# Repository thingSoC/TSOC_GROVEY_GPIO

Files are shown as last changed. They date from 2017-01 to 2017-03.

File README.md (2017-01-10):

# TSOC_GROVEY_GPIO - thingSoC SX1509 GPIO Module :

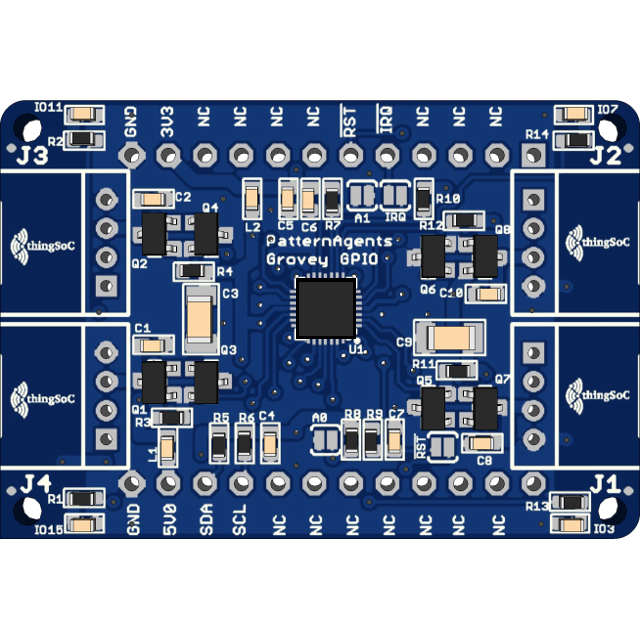
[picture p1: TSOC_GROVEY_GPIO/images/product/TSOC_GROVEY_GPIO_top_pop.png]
thingSoC TSOC_GROVEY_GPIO
[TSOC_GROVEY_GPIO](https://github.com/thingSoC/TSOC_GROVEY_GPIO)

---------------------------------------

## TSOC_GROVEY_GPIO Status <a name="TSOC_GROVEY_GPIO_status"/>

**11/06/2016:** 
Revision 1.0 - Initial Layout released to OSHpark

---------------------------------------
## TSOC_GROVEY_GPIO Model Images

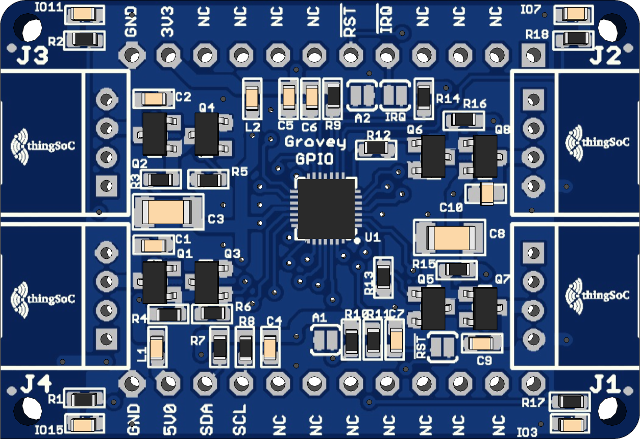
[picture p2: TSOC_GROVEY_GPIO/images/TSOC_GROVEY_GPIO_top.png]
thingSoC TSOC_GROVEY_GPIO
[TSOC_GROVEY_GPIO](https://github.com/thingSoC/TSOC_GROVEY_GPIO)

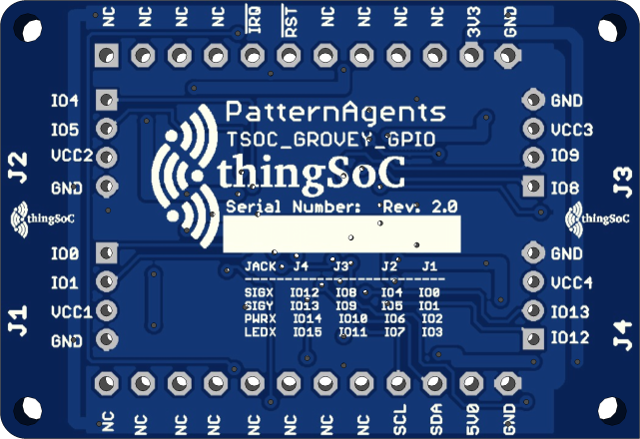
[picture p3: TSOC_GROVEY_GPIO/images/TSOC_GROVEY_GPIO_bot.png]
thingSoC TSOC_GROVEY_GPIO
[TSOC_GROVEY_GPIO](https://github.com/thingSoC/TSOC_GROVEY_GPIO)

---------------------------------------

## TSOC_GROVEY_GPIO Documentation Index <a name="TSOC_GROVEY_GPIO_documentation_index"/>

[TSOC_GROVEY_GPIO Project](http://thingsoc.github.io/projects/TSOC_GROVEY_GPIO.html)

[TSOC_GROVEY_GPIO Hardware](https://github.com/thingSoC/TSOC_GROVEY_GPIO/tree/master/TSOC_GROVEY_GPIO/hardware)

---------------------------------------

## thingSoC Documentation Index <a name="thingSoC_documentation_index"/>

[thingSoC Organization Website](http://thingSoC.github.io)

[thingSoC FAQ - Frequently Asked Questions](http://thingsoc.github.io/support/faq.html)

---------------------------------------

[thingSoC 
*thingSoC*](http://thingsoc.github.io)

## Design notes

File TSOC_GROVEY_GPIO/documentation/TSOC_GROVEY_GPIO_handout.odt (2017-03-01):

thingSoC GROVEY_GPIO Board

Thank you for purchasing a TSOC_GROVEY_GPIO board!
Please see the Getting Started Guide at :
https://github.com/thingSoC/TSOC_GROVEY_GPIO (https://github.com/thingSoC/TSOC_NEOLED)
It has complete instructions and examples to download.

thingSoC GROVEY_GPIO Board

Thank you for purchasing a TSOC_GROVEY_GPIO board!
Please see the Getting Started Guide at :
https://github.com/thingSoC/TSOC_GROVEY_GPIO (https://github.com/thingSoC/TSOC_NEOLED)
It has complete instructions and examples to download.

thingSoC GROVEY_GPIO Board

Thank you for purchasing a TSOC_GROVEY_GPIO board!
Please see the Getting Started Guide at :
https://github.com/thingSoC/TSOC_GROVEY_GPIO (https://github.com/thingSoC/TSOC_NEOLED)
It has complete instructions and examples to download.

thingSoC GROVEY_GPIO Board

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

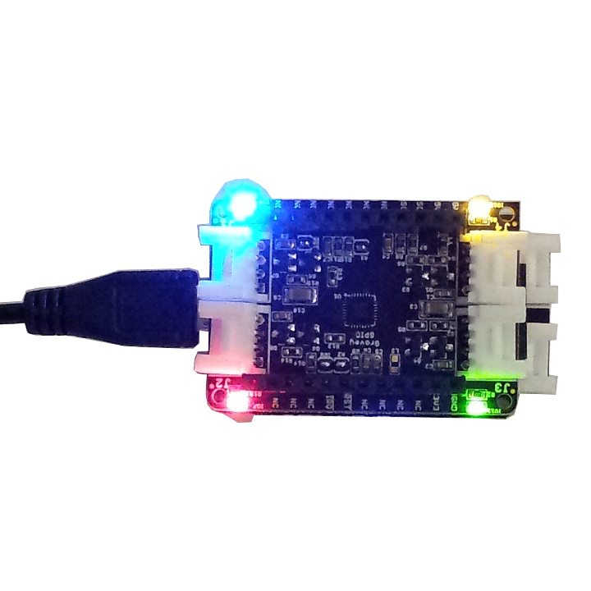
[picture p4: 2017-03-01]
TSOC_GROVEY_GPIO/images/product/tsoc_grovey_gpio_sqr.jpg

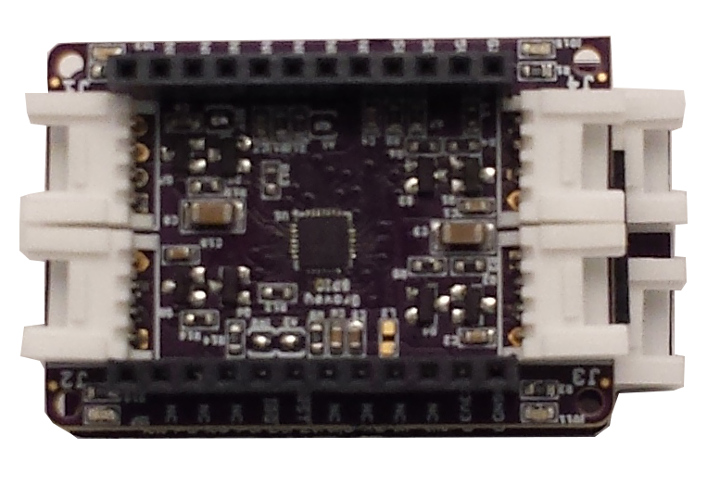
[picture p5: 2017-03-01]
TSOC_GROVEY_GPIO/images/product/tsoc_grovey_gpio.jpg

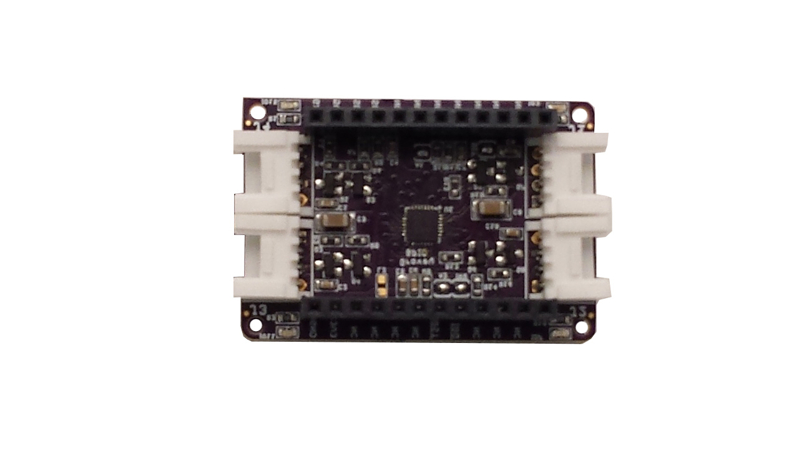
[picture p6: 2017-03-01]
TSOC_GROVEY_GPIO/images/product/tsoc_grovey_gpio3.jpg

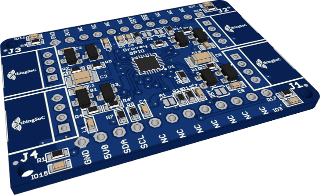
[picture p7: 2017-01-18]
TSOC_GROVEY_GPIO/images/TSOC_GROVEY_GPIO_model.png

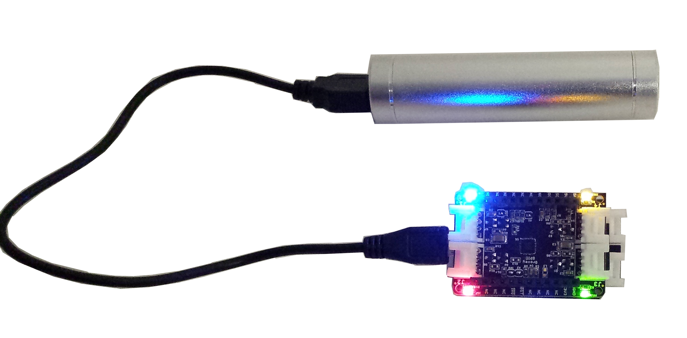
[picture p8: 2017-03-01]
TSOC_GROVEY_GPIO/images/product/tsoc_grovey_gpio_full.jpg

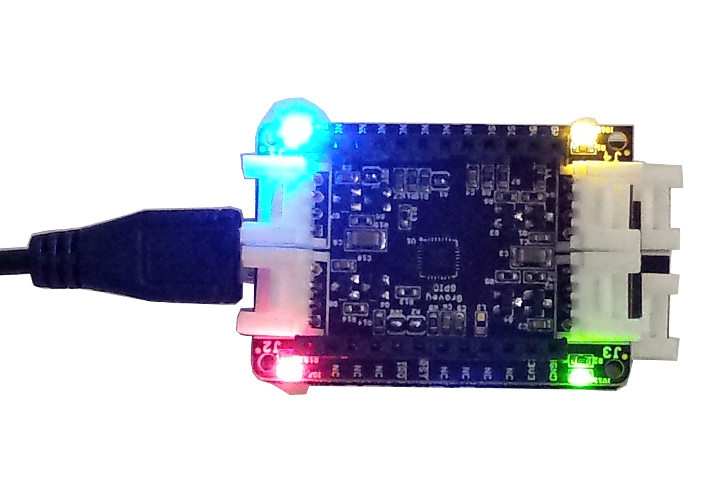
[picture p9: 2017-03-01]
TSOC_GROVEY_GPIO/images/product/tsoc_grovey_gpio2.jpg

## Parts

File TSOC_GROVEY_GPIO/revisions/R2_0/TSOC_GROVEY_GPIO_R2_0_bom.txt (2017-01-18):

Partlist exported from U:/PatternAgents/eagle/TSOC_Modules/TSOC_GROVEY_GPIO/TSOC_GROVEY_GPIO/revisions/R2_0/TSOC_GROVEY_GPIO.sch at 1/17/2017 9:49:19 AM

Qty Value             Device                                        Package         Parts                              Description                         
1   BLUE-0603         SMD-LED-CLEAR-BLUE(0603)                      LED-0603        IO3                                304090045                           
1   RED-0603          LED-SMD-RED-DIFFUSED(0603)                    LED-0603        IO7                                304090042                           
1   GREEN-0603        SMD-LED-CLEAR-GREEN(0603)                     LED-0603        IO11                               304090043                           
1   YELLOW-0603       SMD-LED-CLEAR-YELLOW(0603)                    LED-0603        IO15                               304090044                           
1   SX1509            SX1509                                        QFN-28          U1                                 Semtech SX1509                      
4   BSS138W-7-F       SMD-MOSFET-N-CH-50V-200MA-BSS138W-7-F(SOT-23) SOT-23          Q3, Q4, Q5, Q6                     305030000                           
4   CJ2305            SMD-MOSFET-P-CH-8V-4.1A-CJ2305(SOT-23)        SOT-23          Q1, Q2, Q7, Q8                     305030014                           
2   100nf             CERAMIC-100NF-50V-10%-X7R(0603)               C0603           C5, C7                             302010138                           
6   1uf               CERAMIC-1UF-25V-10%-X7R(0603)                 C0603           C1, C2, C4, C6, C9, C10            302010139                           
2   10uf              CERAMIC-10UF-25V-10%-X5R(1206)                C1206           C3, C8                             302010181                           
6   10K 1/10W         SMD-RES-10K-5%-1/10W(0603)                    R0603           R7, R8, R9, R10, R11, R14          301010293                           
4   1K 1/10W          SMD-RES-1K-5%-1/10W(0603)                     R0603           R1, R2, R17, R18                   301010291                           
8   47K               SMD-RES-47K-5%-1/10W(0603)                    R0603           R3, R4, R5, R6, R12, R13, R15, R16 301010084                           
4   4P-2.0-90D        GROVE-CONNECTOR-DIP-90D(4P-2.0)               HW4-2.0-90D     J1, J2, J3, J4                     320110034                           
1   120OHM-500MA      SMD-FERRITE-CHIP-120-OHM-500MA(0603)          L0603           L1                                 303030001                           
=--------------------------------------------------------------------------------------------------------------------------------
1   DNP               SMD-FERRITE-CHIP-120-OHM-500MA(0603)          L0603           L2                                 303030001

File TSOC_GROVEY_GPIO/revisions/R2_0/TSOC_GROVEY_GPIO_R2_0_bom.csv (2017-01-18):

Part/Designator | Manufacture Part Number/Seeed SKU | Quantity
IO3 | 304090045 | 1
IO7 | 304090042 | 1
IO11 | 304090043 | 1
IO15 | 304090044 | 1
U1 | SX1509IULTRT | 1
Q3, Q4, Q5, Q6 | 305030000 | 4
Q1, Q2, Q7, Q8 | 305030014 | 4
C5, C7 | 302010138 | 2
C1, C2, C4, C6, C9, C10 | 302010139 | 6
C3, C8 | 302010181 | 2
R7, R8, R9, R10, R11, R14 | 301010293 | 6
R1, R2, R17, R18 | 301010291 | 4
R3, R4, R5, R6, R12, R13, R15, R16 | 301010084 | 8
L1 | 303030001 | 1
J1, J2, J3, J4 | 320110034 | 4
J5, J6 | SSW-112-03-G-S | 2

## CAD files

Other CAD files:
TSOC_GROVEY_GPIO/eagleUp/TSOC_GROVEY_GPIO.skp

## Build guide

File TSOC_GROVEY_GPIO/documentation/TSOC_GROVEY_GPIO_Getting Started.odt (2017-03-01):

Welcome to the thingSoC® Grovey GPIO

The TSOC_GROVEY_GPIO is a sixteen (16) port I2C I/O Expander, based on the Semtech SX1509 chip, in an Embedded Module format for the new thingSoC, Internet of Things open source hardware standard.

Getting Started :
The TSOC_GROVEY_GPIO provides sixteen (16) I/O ports, with four(4) Grove compatible connectors. You can use the TSOC_GROVEY_GPIO when :

1. When you need to use 5.0 Volt level I/O with a 3.3V processor.
2. When you need more ports than the 3.3V processor can provide.
3. When you need to control the power of your grove peripherals.

The TSOC_GROVEY_GPIO is an open source hardware project from PatternAgents, LLC,
and you are free to download the schematics, layouts, gerbers, BOMs, etc and build your own boards if you wish.


Default Settings :

Default I2C Address : 0x3E
( Remove Jumper A0 to change address to 0X3F)

Semtech SX1509 I/O Assignment :

I/O 00 : J1 Signal X
I/O 01 : J1 Signal Y
I/O 02 : J1 Power Control
I/O 03 : J1 LED (BLUE)

I/O 04 : J2 Signal X
I/O 05 : J2 Signal Y
I/O 06 : J2 Power Control
I/O 07 : J2 LED (RED)

I/O 08 : J3 Signal X
I/O 09 : J3 Signal Y
I/O 10 : J3 Power Control
I/O 11 : J3 LED (GREEN)

I/O 12 : J4 Signal X
I/O 13 : J4 Signal Y
I/O 14 : J4 Power Control
I/O 15 : J4 LED (YELLOW)


Safe Handling Precautions :

1) Always remove/unplug all power before inserting or removing peripherals.
2) Always ground yourself by touching a ground point before handling your boards.
3) Use a static safe bag when transporting your TSOC_GROVEY_GPIO board.

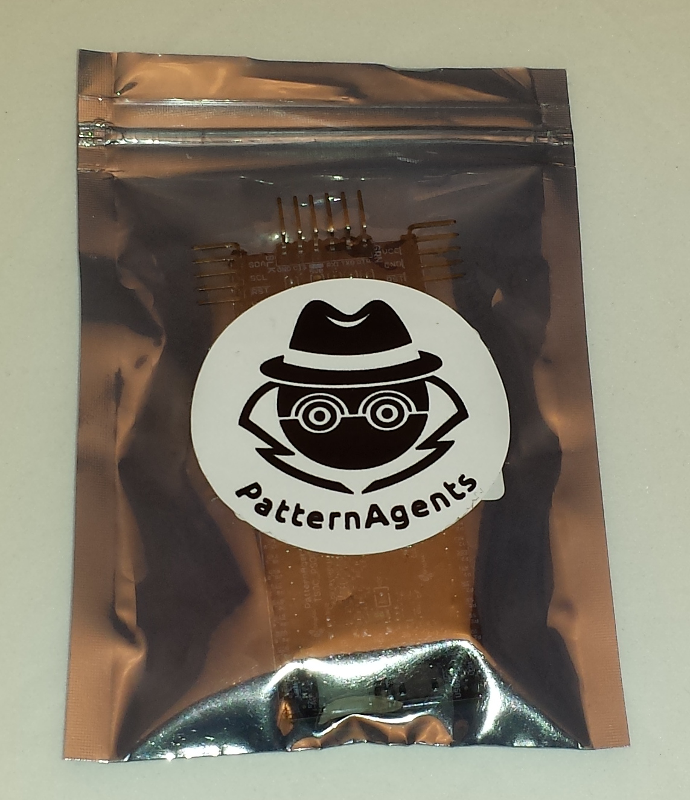
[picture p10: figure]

Adding Grove Peripherals :
The TSOC_GROVEY_GPIO board supports Grove peripherals.
1) Grove connectors are polarized, and can only be plugged in one way.

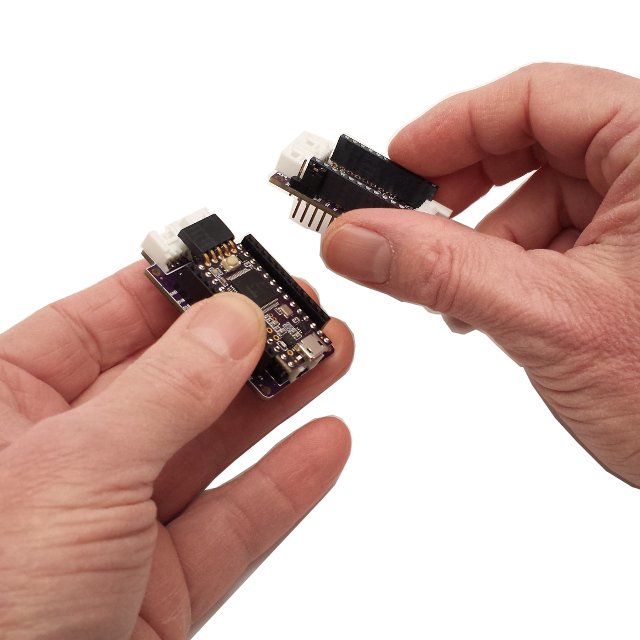
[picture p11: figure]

Adding Mikrobus Peripherals :
The TSOC_GROVEY_GPIO board supports Grove peripherals and can interoperate with Mikrobus peripherals.

1) Make sure to align the SQUARE/CUT edges of the Mikrobus board together to insure that
the polarity is correct. Push down evenly to seat the boards in the socket.

2) Note that the "stacking pins" are somewhat longer by design, and there will be some
extra space between the boards when using stacking connectors.

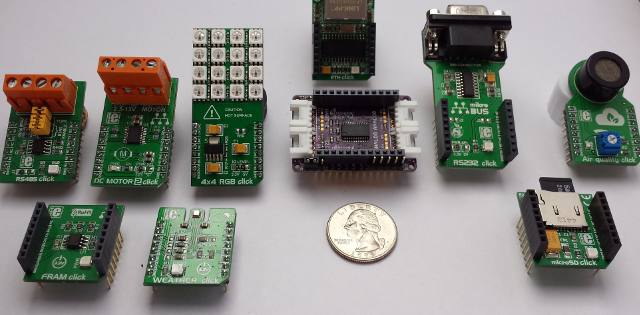
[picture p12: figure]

For more information and examples :

Complete documentation, including schematics, layouts, gerbers, and Bill of Materials (BOM) are available on the thingSoC website at :

https://github.com/thingSoC/TSOC_GROVEY_GPIO/tree/master/TSOC_GROVEY_GPIO (https://github.com/thingSoC/TSOC_PSoC4L/tree/master/TSOC_PSoC4L)

There is also a project Wiki available for asking questions and more information at :

https://github.com/thingSoC/TSOC_GROVEY_GPIO/wiki (https://github.com/thingSoC/TSOC_PSoC4L/wiki)

thingSoC® Grovey GPIO Features :

The TSOC_GROVEY_GPIO is a low cost, embeddable module featuring a Semtech SX1509 device :

- 16 Port I2C GPIO Expander
- 0 Hz to 400KHz I2C Bus Speed
- 3.3 Volt or 5.0 Volt operation
- Optional Active Low Reset Line
- Low Standby current
- Builtin ESD protection
- GPIO (16 Channels)
- Four (4) Color LEDs (Red, Green, Blue, Yellow)
- thingSoC Compliant Module
- Mikrobus Compatible Module (http://www.mikroe.com/mikrobus/)
- Support SeeedStudio Grove Peripherals

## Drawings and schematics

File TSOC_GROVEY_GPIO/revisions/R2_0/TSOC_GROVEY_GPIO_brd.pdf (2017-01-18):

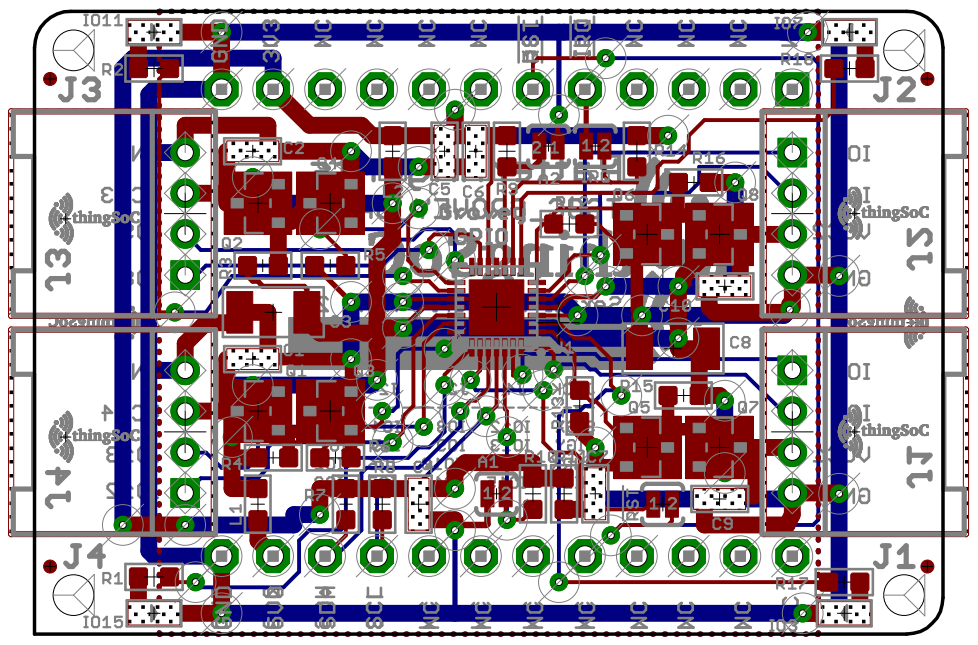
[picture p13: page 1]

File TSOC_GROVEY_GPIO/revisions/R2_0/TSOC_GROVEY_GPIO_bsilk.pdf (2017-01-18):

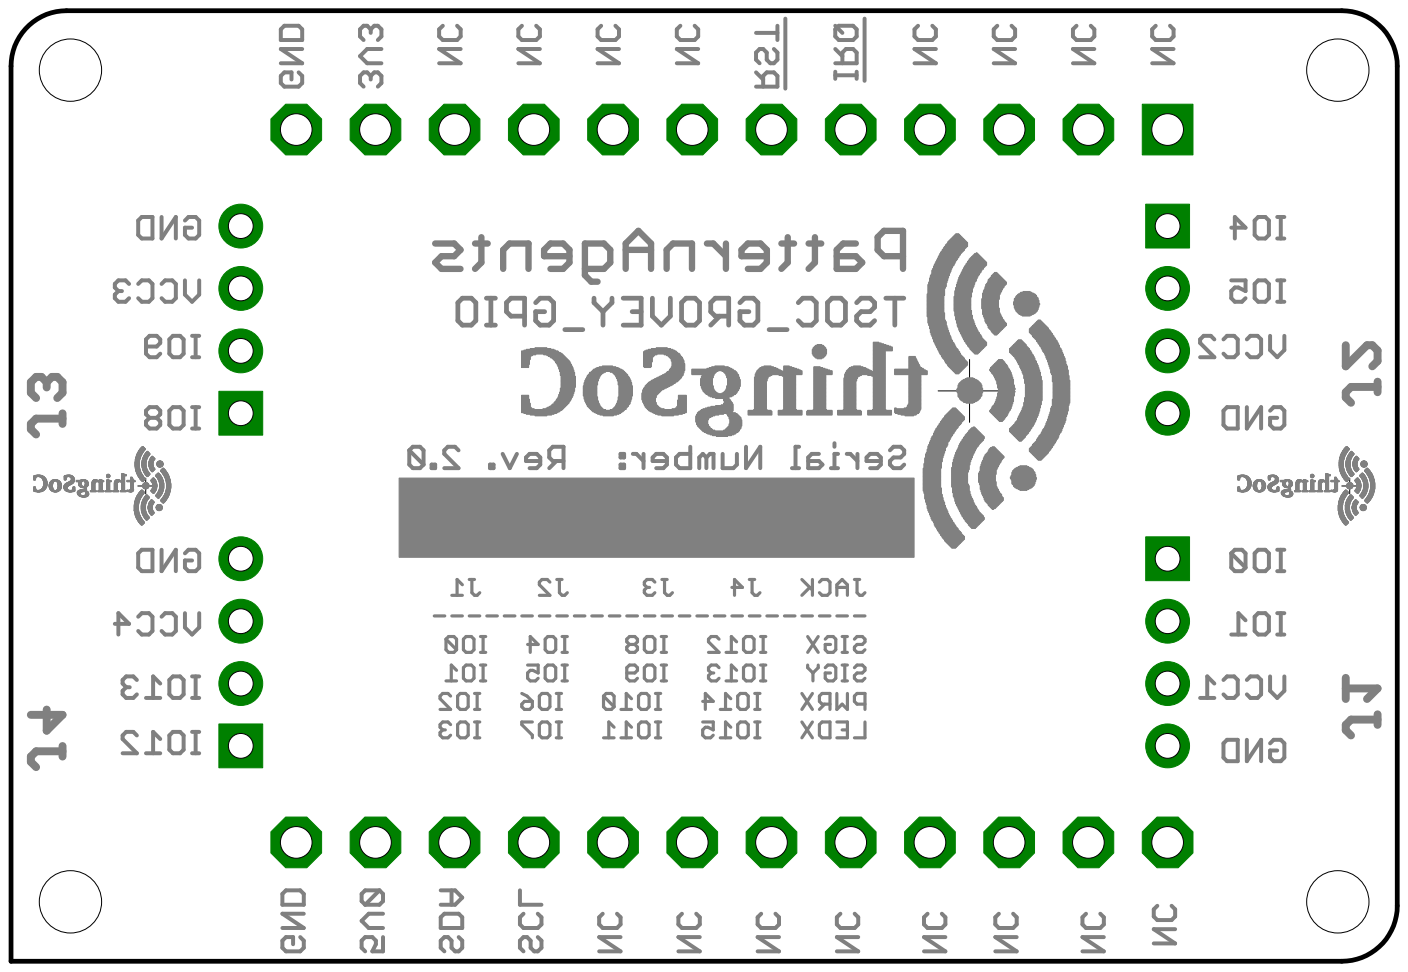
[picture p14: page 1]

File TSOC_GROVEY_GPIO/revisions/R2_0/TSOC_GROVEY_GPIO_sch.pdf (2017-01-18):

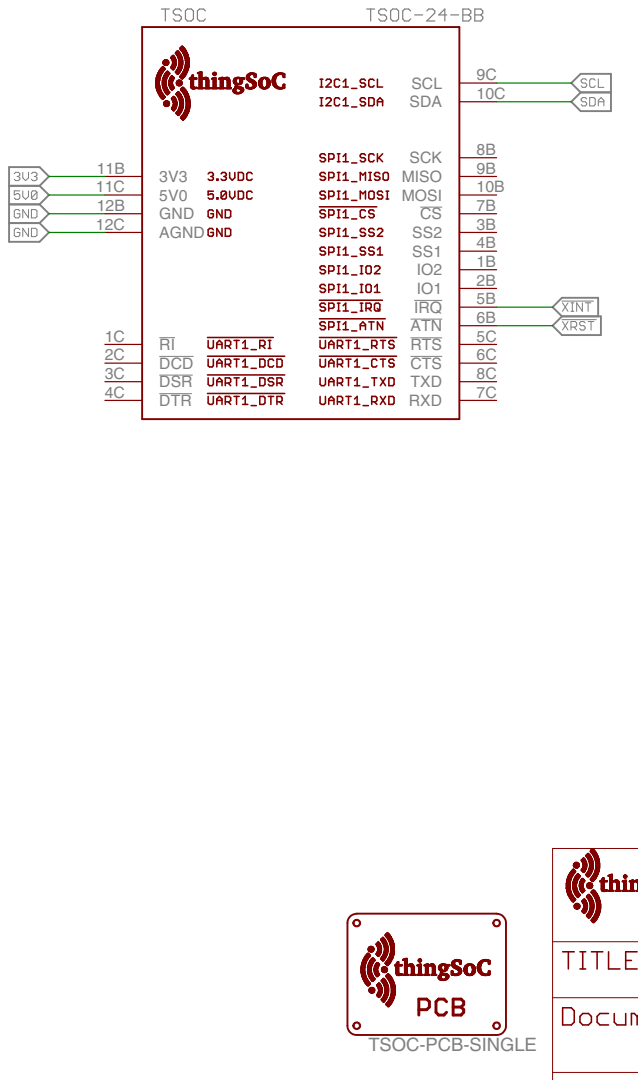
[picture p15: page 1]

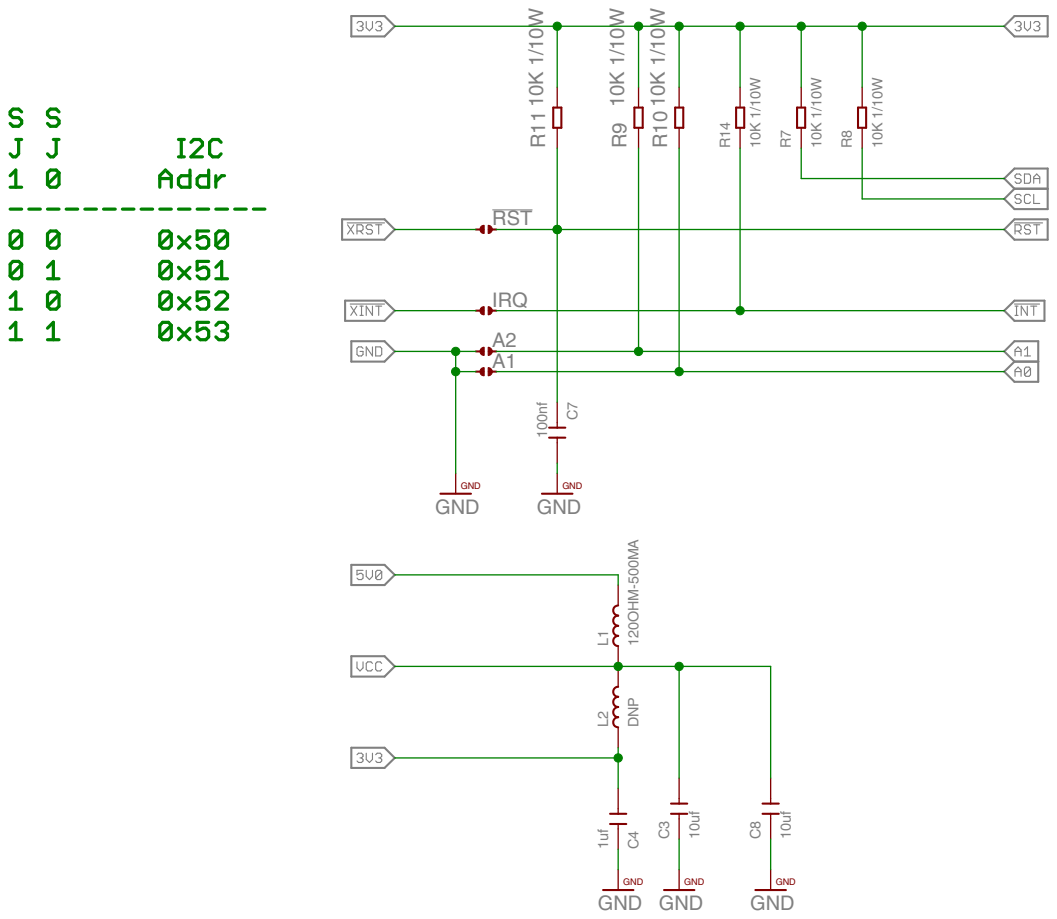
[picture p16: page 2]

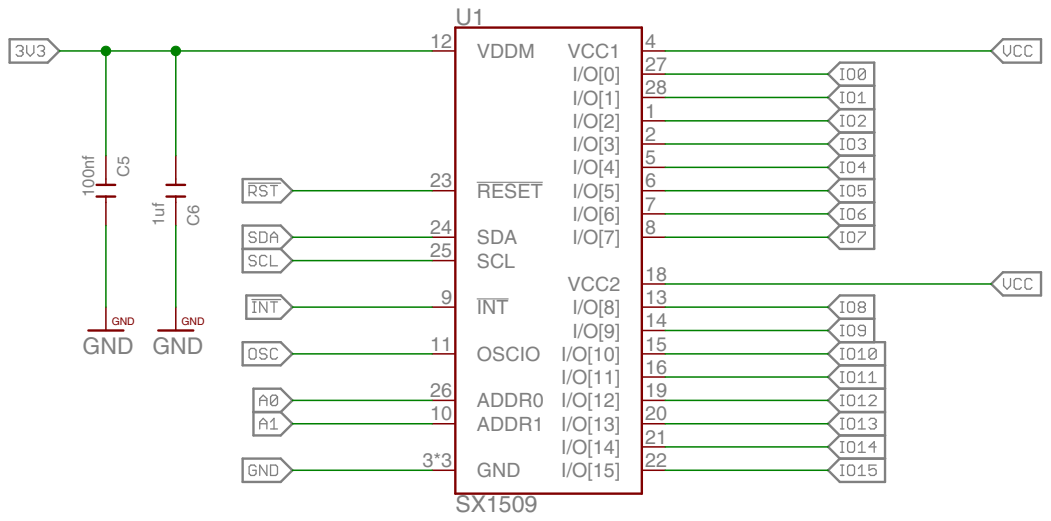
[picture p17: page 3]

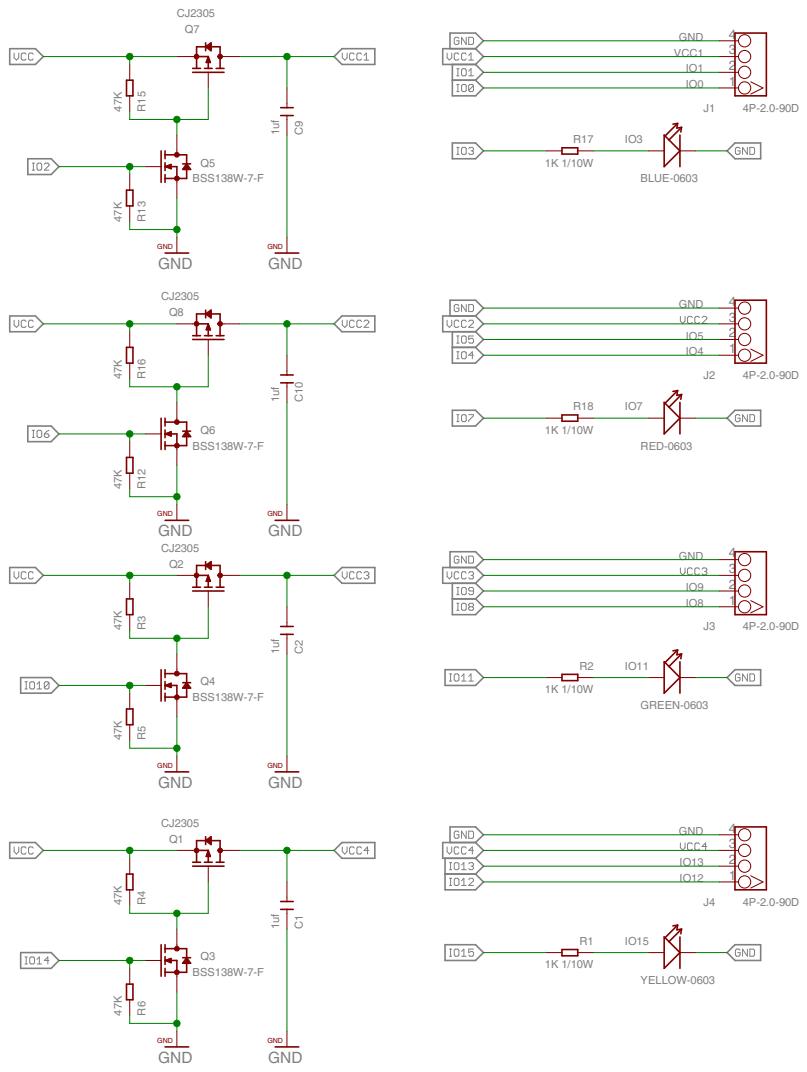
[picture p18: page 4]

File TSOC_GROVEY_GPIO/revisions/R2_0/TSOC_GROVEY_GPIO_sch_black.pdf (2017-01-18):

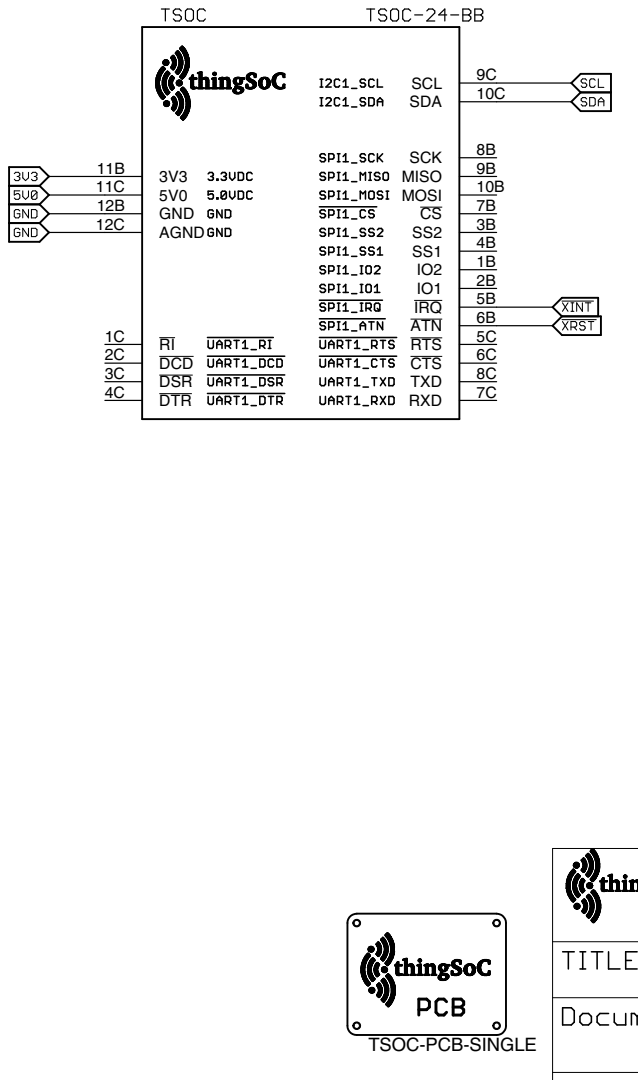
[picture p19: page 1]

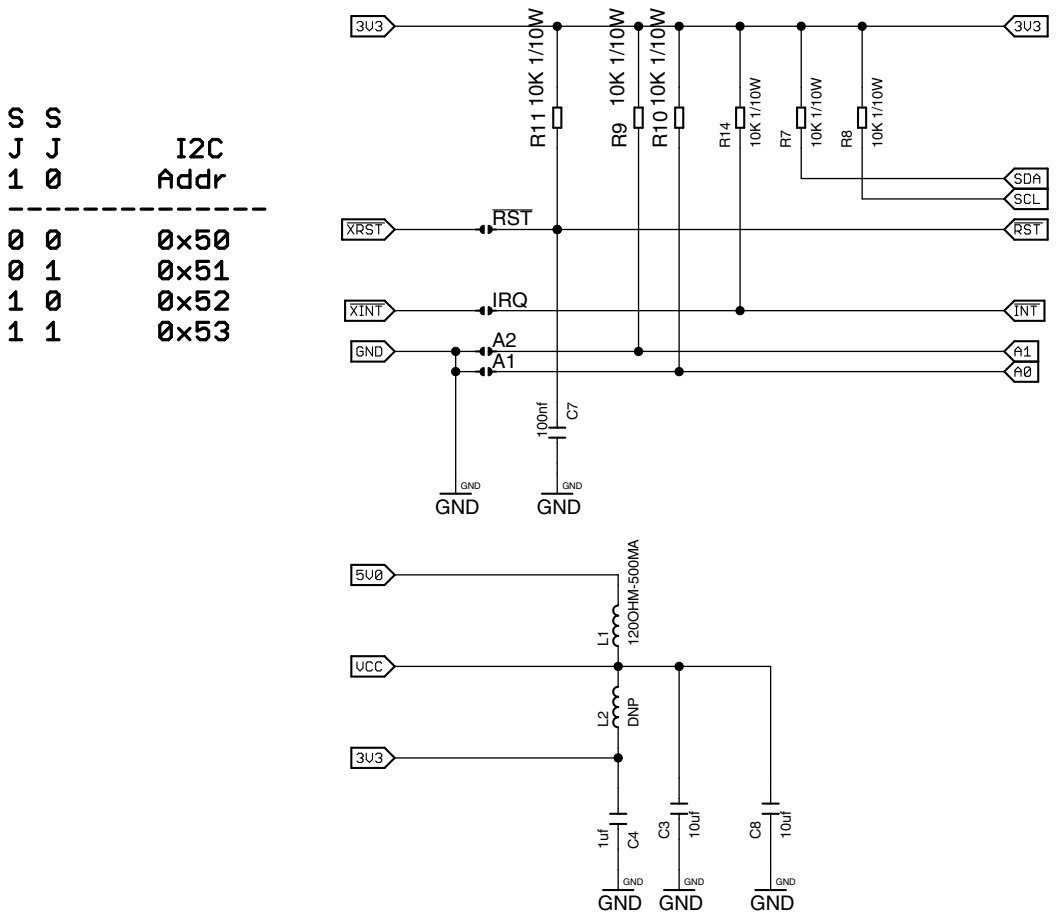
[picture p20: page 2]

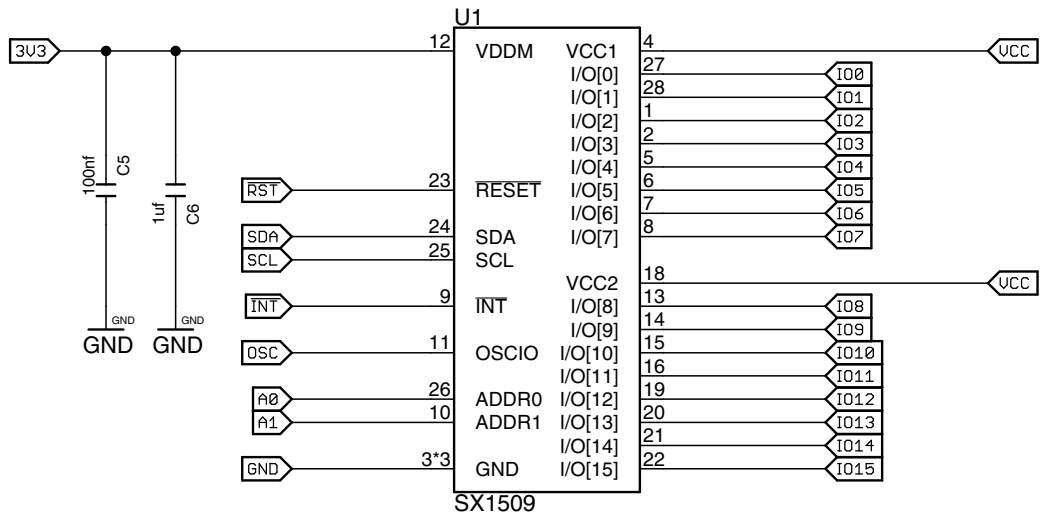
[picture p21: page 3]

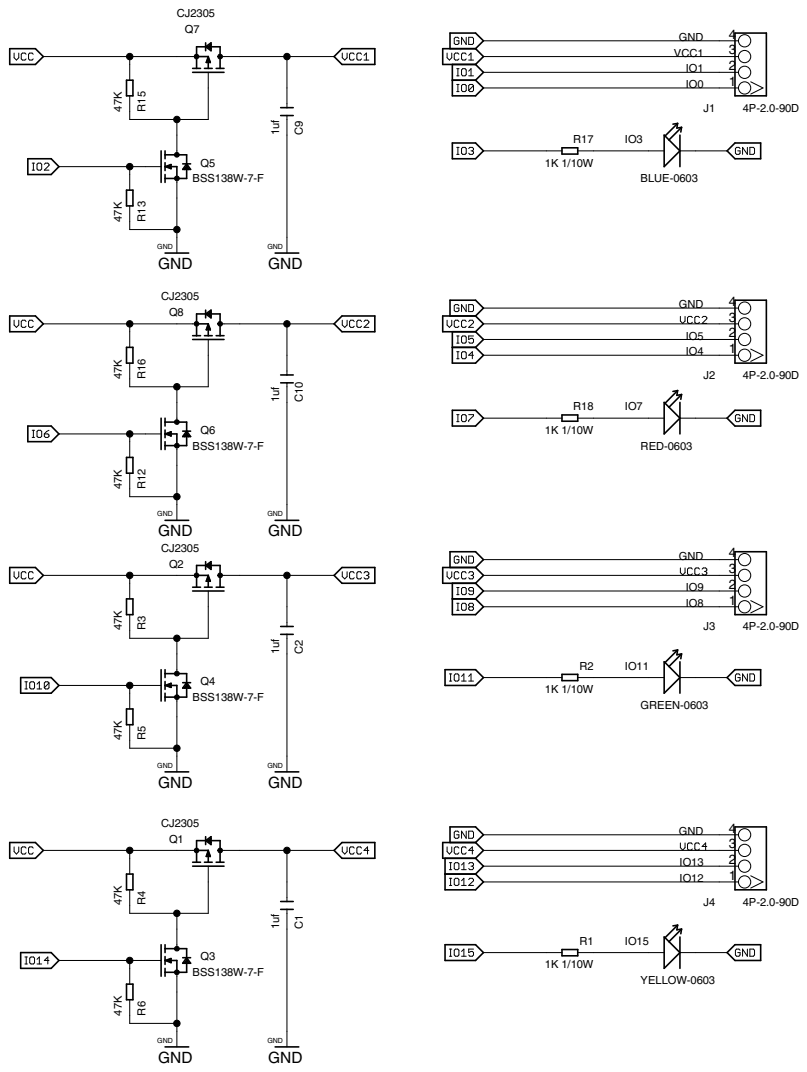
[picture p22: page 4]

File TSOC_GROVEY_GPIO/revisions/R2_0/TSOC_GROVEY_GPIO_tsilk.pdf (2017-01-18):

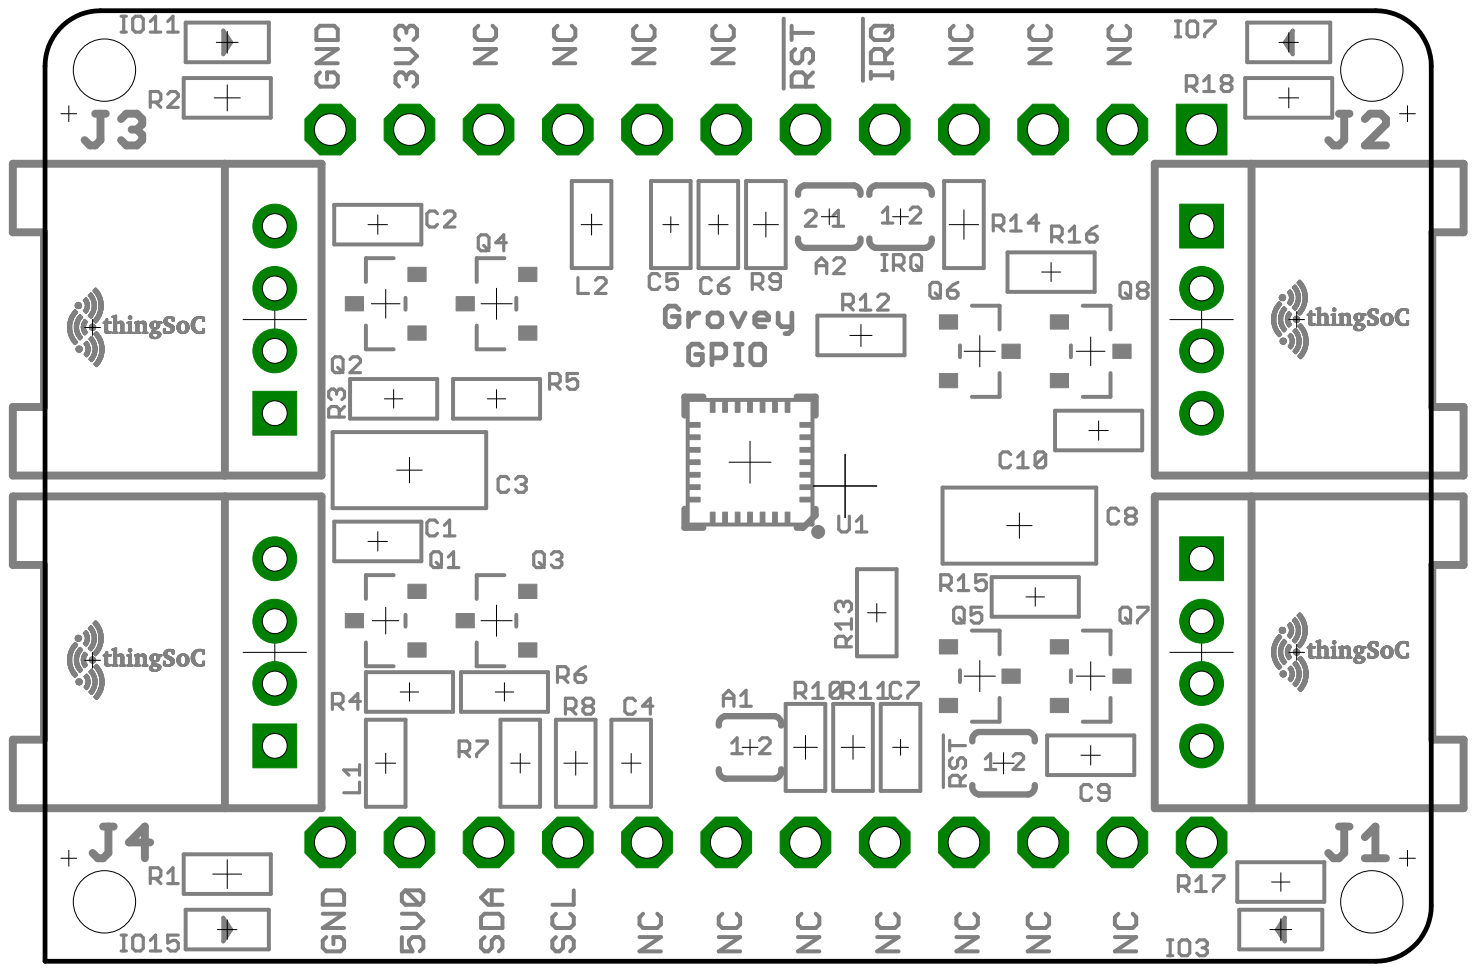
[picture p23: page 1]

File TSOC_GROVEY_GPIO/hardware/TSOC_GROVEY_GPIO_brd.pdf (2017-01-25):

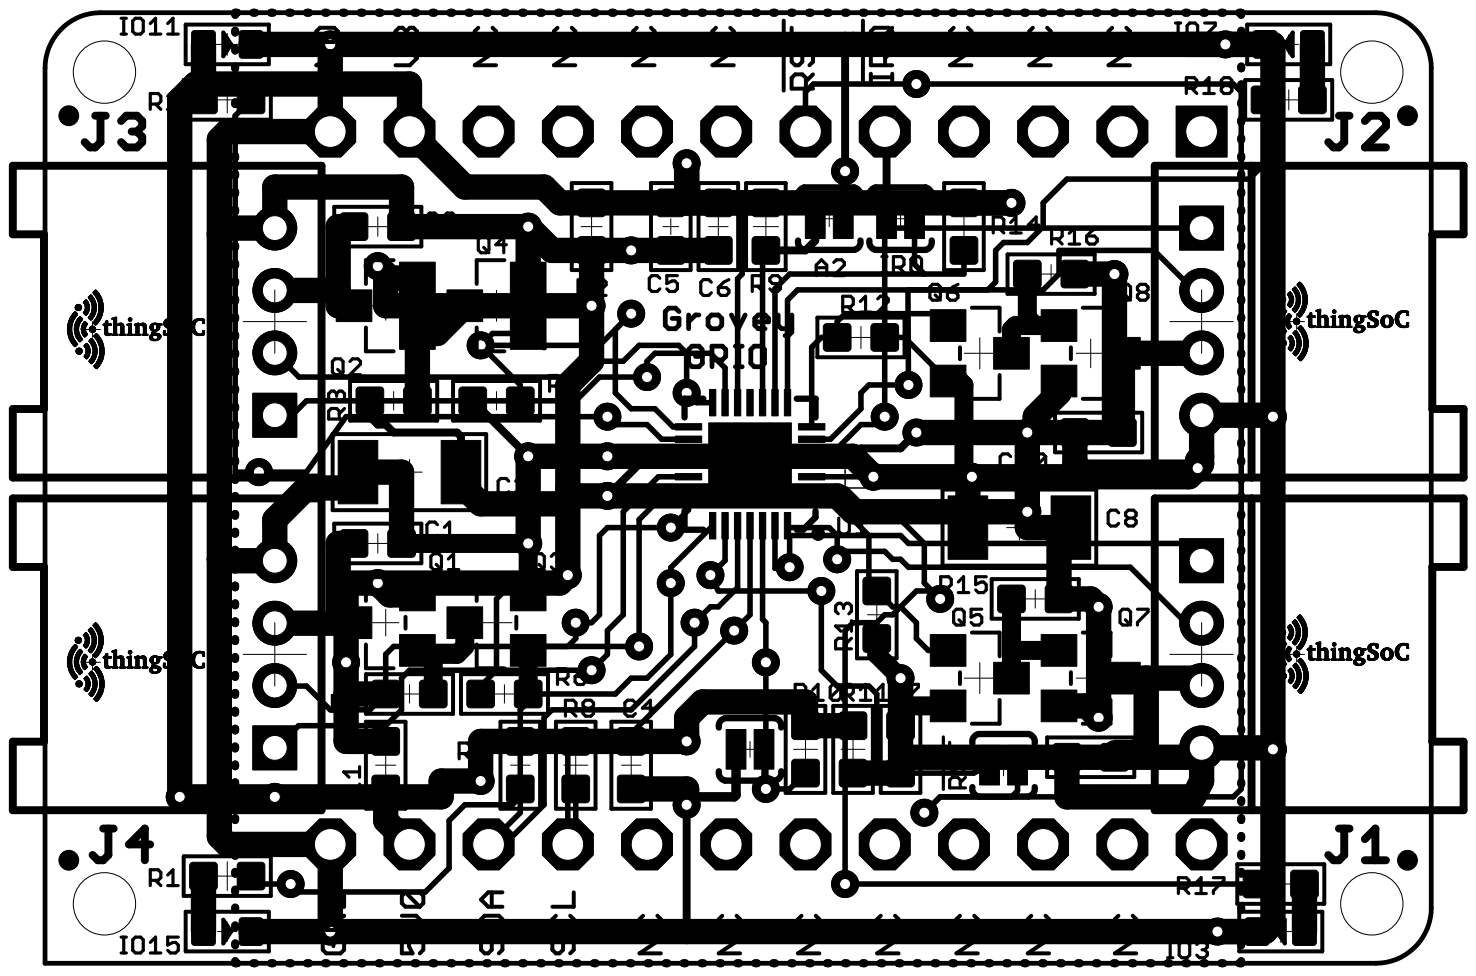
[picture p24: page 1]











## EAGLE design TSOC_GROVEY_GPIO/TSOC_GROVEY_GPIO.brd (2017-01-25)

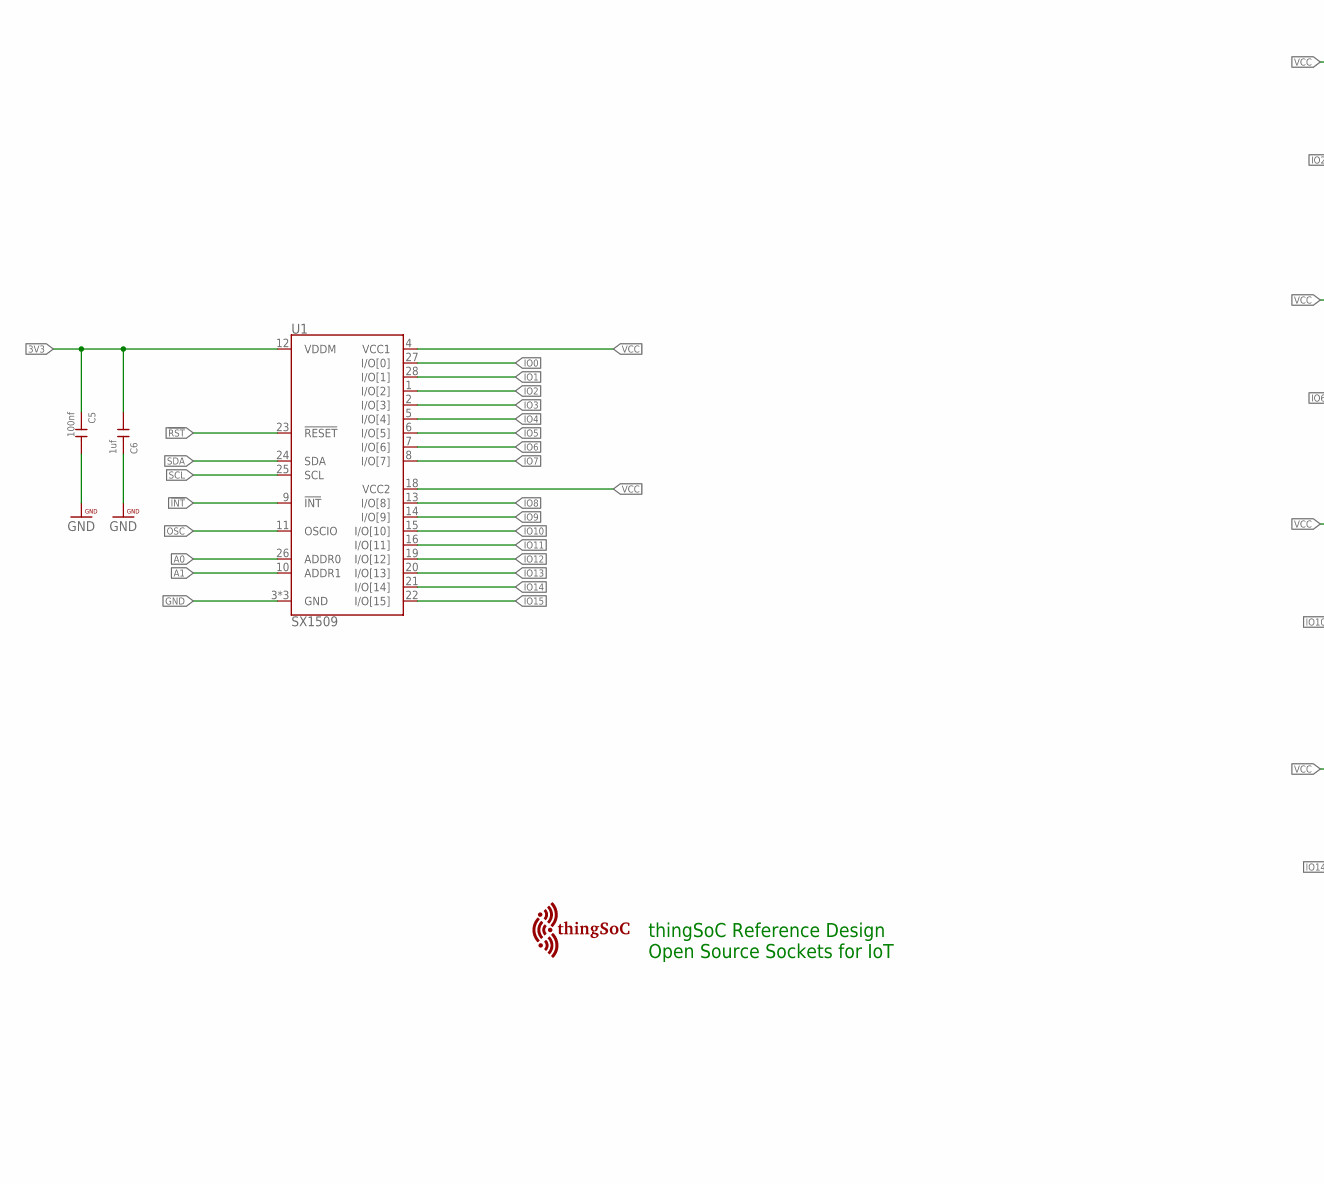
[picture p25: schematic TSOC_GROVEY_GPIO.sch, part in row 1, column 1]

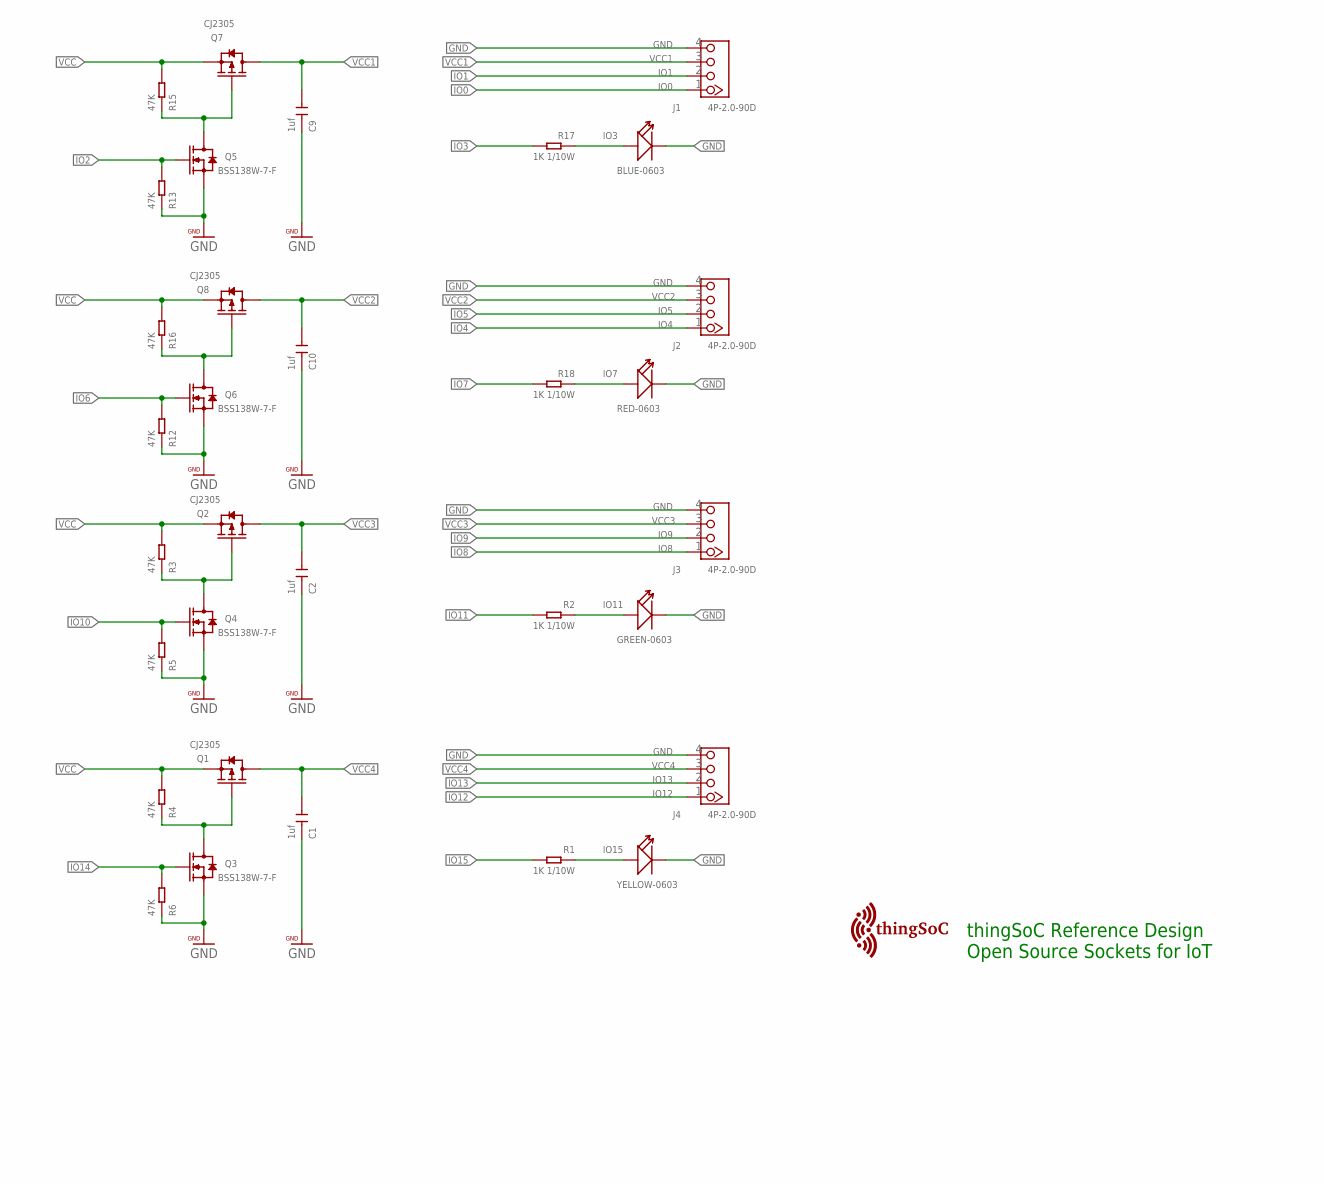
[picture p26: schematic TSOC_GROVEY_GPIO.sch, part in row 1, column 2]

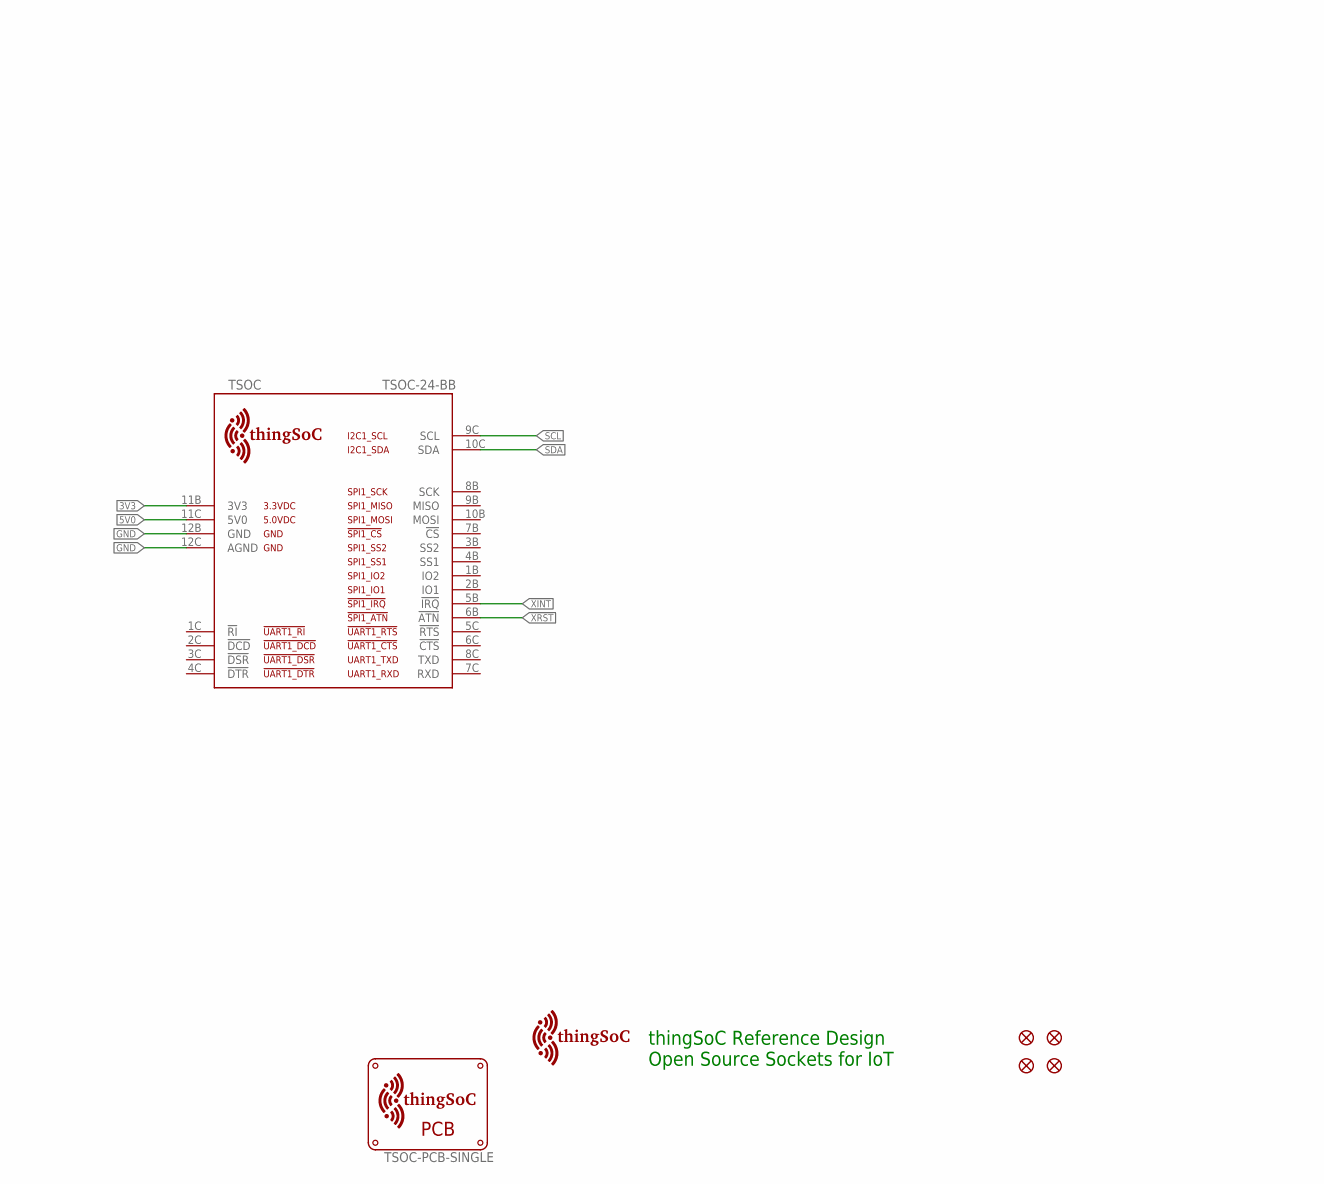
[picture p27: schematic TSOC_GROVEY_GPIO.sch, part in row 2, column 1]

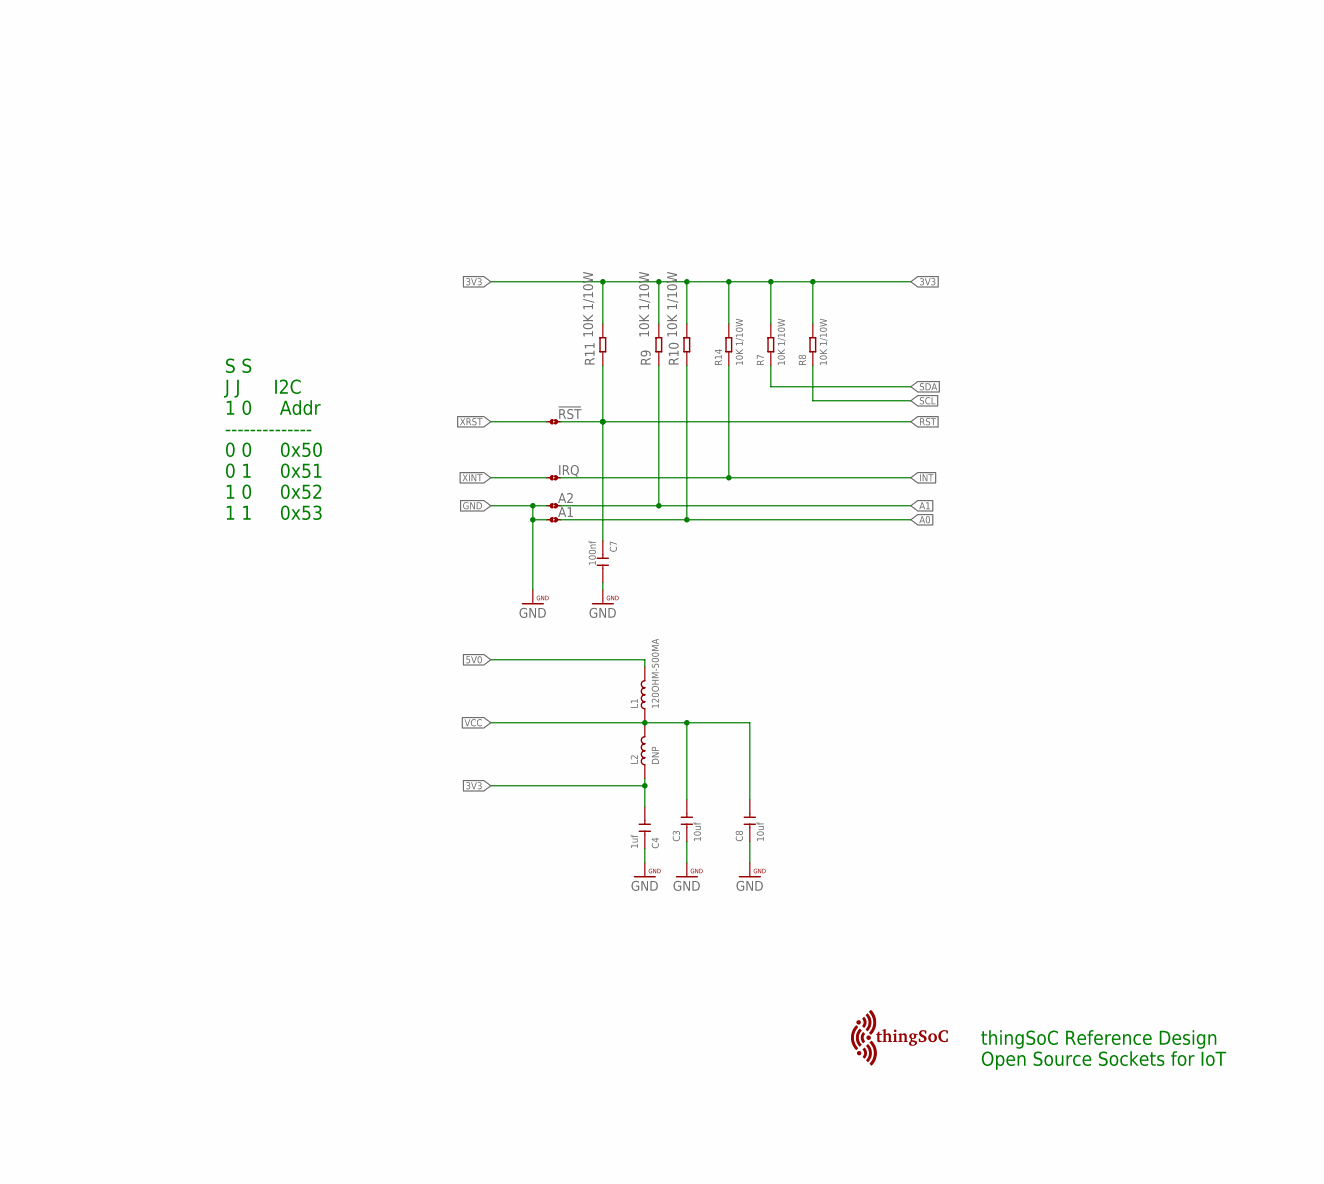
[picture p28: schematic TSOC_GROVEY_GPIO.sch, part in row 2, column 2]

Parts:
!RST: NO; JMP-2-NO
$$U$1, $$U$2: TSOC-LOGO-SMALL; TSOC-LOGO-SML
A1, A2: NO; JMP-2-NO
C1, C2, C4, C6, C9, C10: 1uf; C0603
C3, C8: 10uf; C1206
C5, C7: 100nf; C0603
FID1, FID2, FID3, FID4: FIDUCIALUFIDUCIAL; MICRO-FIDUCIAL
IO3: BLUE-0603; LED-0603
IO7: RED-0603; LED-0603
IO11: GREEN-0603; LED-0603
IO15: YELLOW-0603; LED-0603
IRQ: NO; JMP-2-NO
J1, J2, J3, J4: 4P-2.0-90D; HW4-2.0-90D
L1: 120OHM-500MA; L0603
L2: DNP; L0603
Q1, Q2, Q7, Q8: CJ2305; SOT-23
Q3, Q4, Q5, Q6: BSS138W-7-F; SOT-23
R1, R2, R17, R18: 1K 1/10W; R0603
R3, R4, R5, R6, R12, R13, R15, R16: 47K; R0603
R7, R8, R9, R10, R11, R14: 10K 1/10W; R0603
TSOC: TSOC-24-BB; TSOC-BB-S24
U1: SX1509; QFN-28
U$3: TSOC-PCB-SINGLE; TSOC-BB-BRD-DIM
U$101: TSOC-LOGO-LRG
U$102: TSOC-LOGO-SMALL; TSOC-LOGO-SML

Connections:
3V3: C4.2, C5.1, C6.2, L2.1, R7.2, R8.2, R9.2, R10.2, R11.2, R14.2, TSOC.11B (3V3), U1.12 (VDDM)
5V0: L1.2, TSOC.11C (5V0)
!INT: IRQ.2, R14.1, U1.9 (!INT)
!RST: !RST.1, C7.1, R11.1, U1.23 (!RESET)
!XINT: IRQ.1, TSOC.5B (!IRQ)
!XRST: !RST.2, TSOC.6B (!ATN)
A0: A1.2, R10.1, U1.26 (ADDR0)
A1: A2.2, R9.1, U1.10 (ADDR1)
GND: A1.1, A2.1, C1.1, C2.1, C3.1, C4.1, C5.2, C6.1, C7.2, C8.1, C9.1, C10.1, IO3.-, IO7.-, IO11.-, IO15.-, J1.4, J2.4, J3.4, J4.4, Q3.2 (S), Q4.2 (S), Q5.2 (S), Q6.2 (S), R5.1, R6.1, R12.1, R13.1, TSOC.12B (GND), TSOC.12C (AGND), U1.3 (GND), U1.17 (GND), U1.29 (GND)
IO0: J1.1, U1.27 (I/O[0])
IO1: J1.2, U1.28 (I/O[1])
IO2: Q5.1 (G), R13.2, U1.1 (I/O[2])
IO3: R17.2, U1.2 (I/O[3])
IO4: J2.1, U1.5 (I/O[4])
IO5: J2.2, U1.6 (I/O[5])
IO6: Q6.1 (G), R12.2, U1.7 (I/O[6])
IO7: R18.2, U1.8 (I/O[7])
IO8: J3.1, U1.13 (I/O[8])
IO9: J3.2, U1.14 (I/O[9])
IO10: Q4.1 (G), R5.2, U1.15 (I/O[10])
IO11: R2.2, U1.16 (I/O[11])
IO12: J4.1, U1.19 (I/O[12])
IO13: J4.2, U1.20 (I/O[13])
IO14: Q3.1 (G), R6.2, U1.21 (I/O[14])
IO15: R1.2, U1.22 (I/O[15])
LED1: IO11.+, R2.1
LED2: IO7.+, R18.1
LED3: IO3.+, R17.1
LED4: IO15.+, R1.1
unnamed: Q2.1 (G), Q4.3 (D), R3.1
unnamed: Q1.1 (G), Q3.3 (D), R4.1
unnamed: Q5.3 (D), Q7.1 (G), R15.1
unnamed: Q6.3 (D), Q8.1 (G), R16.1
OSC: U1.11 (OSCIO)
SCL: R8.1, TSOC.9C (SCL), U1.25 (SCL)
SDA: R7.1, TSOC.10C (SDA), U1.24 (SDA)
VCC: C3.2, C8.2, L1.1, L2.2, Q1.2 (S), Q2.2 (S), Q7.2 (S), Q8.2 (S), R3.2, R4.2, R15.2, R16.2, U1.4 (VCC1), U1.18 (VCC2)
VCC1: C9.2, J1.3, Q7.3 (D)
VCC2: C10.2, J2.3, Q8.3 (D)
VCC3: C2.2, J3.3, Q2.3 (D)
VCC4: C1.2, J4.3, Q1.3 (D)

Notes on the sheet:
S S J J I2C 1 0 Addr -------------- 0 0 0x50 0 1 0x51 1 0 0x52 1 1 0x53
thingSoC Reference Design Open Source Sockets for IoT

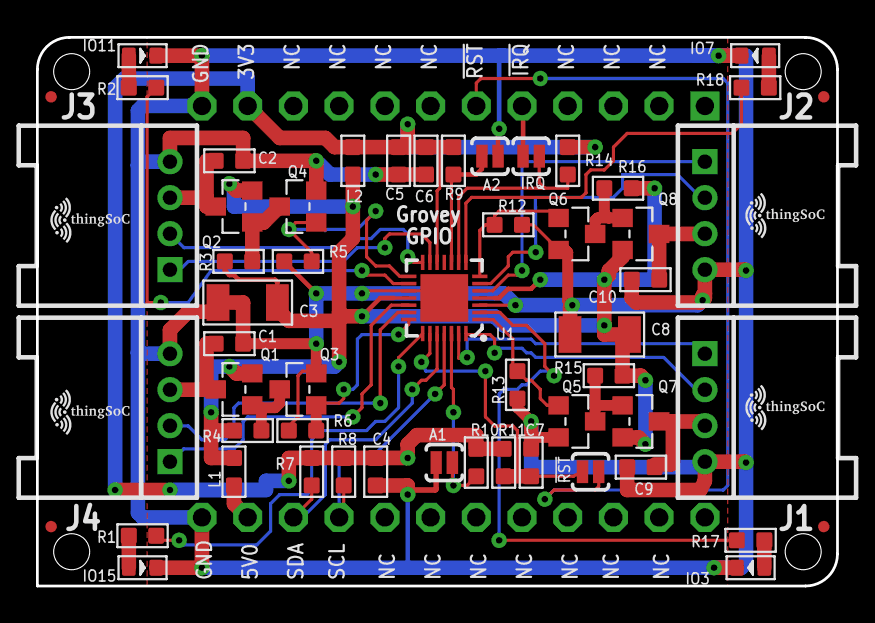
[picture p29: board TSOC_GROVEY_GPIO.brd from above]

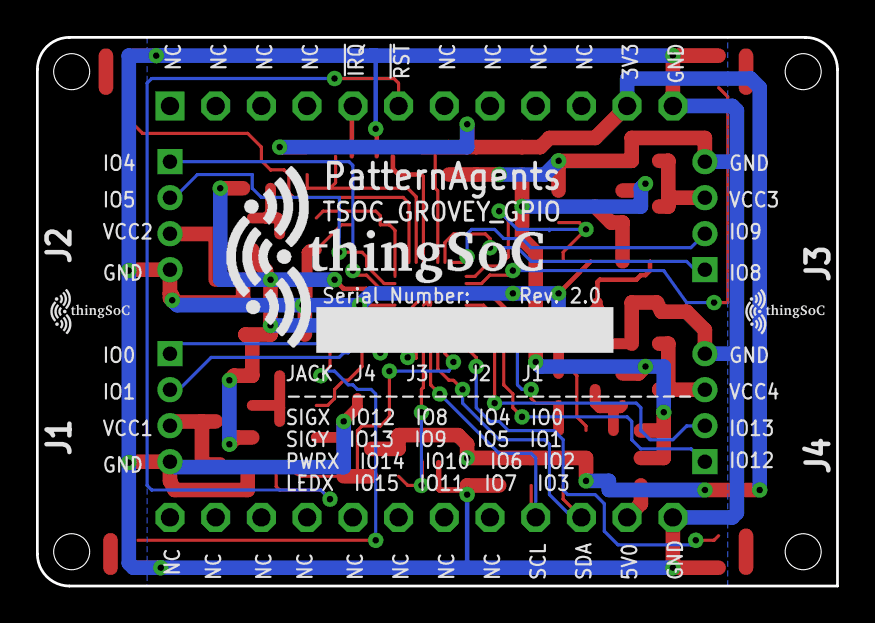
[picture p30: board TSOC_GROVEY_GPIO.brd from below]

Board: 2 copper layers, 44.5 x 30.5 mm, 64 parts (3 on the bottom side), 40 nets.

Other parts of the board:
U$1, U$2, U$100: TSOC-LOGO-SMALL; TSOC-LOGO-SML

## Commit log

2017-01-10 update documentation
    [TSOC_GROVEY_GPIO.brd, TSOC_GROVEY_GPIO.sch, TSOC_GROVEY_GPIO.skp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]
2017-01-18 update to Rev2.0
    [TSOC_GROVEY_GPIO.brd, TSOC_GROVEY_GPIO.sch, TSOC_GROVEY_GPIO.skp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]
2017-01-25 update silkscreen
    [TSOC_GROVEY_GPIO.brd]

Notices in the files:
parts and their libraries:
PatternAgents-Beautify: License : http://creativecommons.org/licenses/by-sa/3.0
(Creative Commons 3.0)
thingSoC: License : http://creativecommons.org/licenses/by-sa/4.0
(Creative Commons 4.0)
